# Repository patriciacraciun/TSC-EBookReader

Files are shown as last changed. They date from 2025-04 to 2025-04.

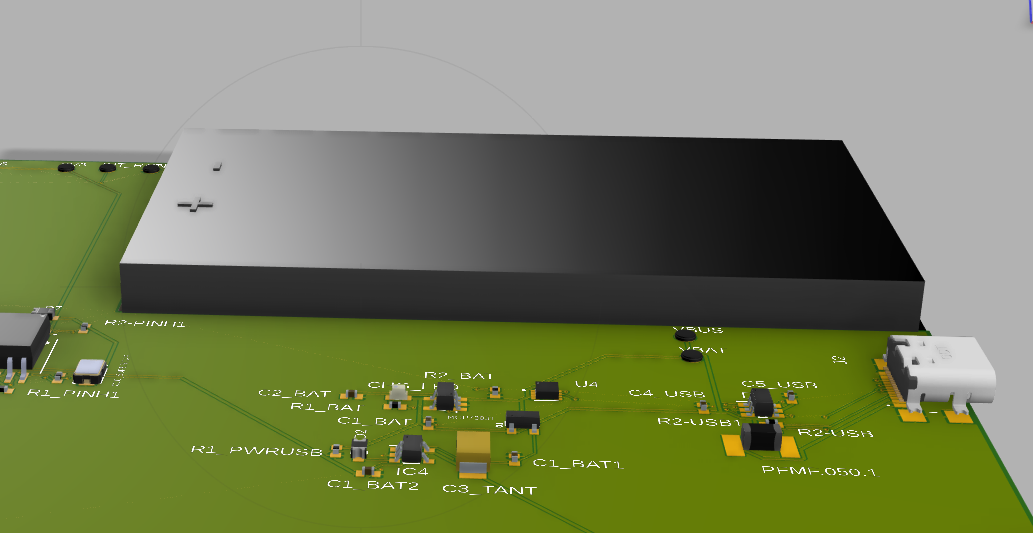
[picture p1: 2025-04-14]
Images/Screenshot 2025-04-14 140928.png

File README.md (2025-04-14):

# README 

## Descriere Generala

Acest proiect reprezinta un sistem integrat cu afisaj E-Paper, conectivitate wireless si mai multi senzori. Totul este construit in jurul microcontrollerului ESP32-C6, care ofera suport pentru WiFi 6 si Bluetooth LE.
Proiectul include atat partea de incarcare si monitorizare a bateriei, cat si stocare externa si masurare a conditiilor de mediu.

---

## Etapele de Implementare

- Am inceput cu realizarea schemei electrice, conectand toate componentele relevante la ESP32-C6.
- Apoi am trecut la layout-ul PCB-ului in 2D, unde am rutat liniile de date si alimentare.
- Am creat planuri de masa (GND plane) atat pe stratul superior, cat si inferior.
- Am folosit reguli custom pentru latimea traseelor de alimentare si distantele minime fata de alte semnale.
- Conectorii au fost pozitionati astfel incat sa fie usor accesibili (ex: Qwiic pentru senzori externi).
- Am adaugat pad-uri de test (TP) pentru debugging mai usor dupa asamblare.
- Am generat modele 3D pentru a verifica compatibilitatea mecanica si pozitionarea componentelor in carcasa.
---











## Diagrama Bloc

```text
         +------------+
         |  Baterie   |
         +------------+
               |
               v
       +----------------+
       |  Charging IC   |<-- USB-C
       +----------------+
               |
               v
       +----------------+
       |      LDO       | --> 3.3V
       +----------------+
               |
      +--------+--------+--------+--------+--------+
      v        v        v        v        v
   +------+ +--------+ +------+ +------+ +--------+
   | ESP  | |Display | | RTC  | | BME  | | Butoane|
   | -C6  | |(SPI)   | |(I2C) | |(I2C) | |(GPIO)  |
   +------+ +--------+ +------+ +------+ +--------+
               |
               v
           +---------+
           | Flash   |
           |  NOR    |
           | (SPI)   |
           +---------+
               |
               v
           +---------+
           | SD Card |
           |  (SPI)  |
           +---------+
```

---

## BOM (Bill Of Materials)

| Componenta | Link Cumparare | Datasheet 
|---|---|---
| 112A-TAAR-R03 ATTEND | https://store.comet.srl.ro/Catalogue/Product/43497/ | https://www.snapeda.com/parts/112A-TAAR-R03/Attend/datasheet/ 
| BD5229G-TR | https://www.digikey.com/en/products/detail/rohm-semiconductor/BD5229G-TR/3663792 | https://fscdn.rohm.com/en/products/databook/datasheet/ic/power/voltage_detector/bd52xxg-e.pdf 
| ESP32 WROVER BME680 Sensor | https://store.comet.srl.ro/Catalogue/Product/50164/ | https://www.bosch-sensortec.com/media/boschsensortec/downloads/datasheets/bst-bme680-ds001.pdf 
| LED CHG_LED | https://ro.mouser.com/ProductDetail/Kingbright/KP-1608SURCK?qs=2JU0tDl2GZ3FuyEWfBV1%2Fg== | https://www.snapeda.com/parts/KP-1608SURCK/Kingbright/datasheet/ 
| Condensator C0402 | https://ro.mouser.com/c/passive-components/capacitors/ceramic-capacitors/?q=CC0402 | https://componentsearchengine.com/Datasheets/2/CC0402MRX5R5BB106.pdf 
| Condensator Tant | https://ro.mouser.com/ProductDetail/KYOCERA-AVX/TAJW107M010RNJ?qs=Wtp%252Bf%2FAeVqIH8v1VxV%252B1Rg%3D%3D | https://ro.mouser.com/datasheet/2/40/TAJ-3165264.pdf 
| Q1 DMG2305UX-7 | https://www.digikey.com/en/products/detail/diodes-incorporated/DMG2305UX-7/4340666 | https://www.diodes.com/assets/Datasheets/DMG2305UX.pdf 
| RTC MODULE DS3231SN# | https://www.snapeda.com/parts/DS3231SN%23/Analog+Devices/view-part/?ref=eda | https://www.snapeda.com/parts/DS3231SN%23/Analog%20Devices/datasheet/ 
| ESP32 C6 WROOM-1-N8 | https://ro.mouser.com/ProductDetail/Espressif-Systems/ESP32-C6-WROOM-1-N8?qs=8Wlm6%252BaMh8ST02Gmwp74cw%3D%3D | https://www.snapeda.com/parts/ESP32-C6-WROOM-1-N8/Espressif%20Systems/datasheet/ 
| FH34SRJ-24S-0.5SH(99) | https://ro.mouser.com/ProductDetail/Hirose-Connector/FH34SRJ-24S-0.5SH99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 | https://www.snapeda.com/parts/FH34SRJ-24S-0.5SH(99)/Hirose%20Connector/datasheet/ 
| MAX 17048G+T10 | https://www.snapeda.com/parts/MAX17048G+T10/Analog+Devices/view-part/?ref=eda | https://www.snapeda.com/parts/MAX17048G+T10/Analog%20Devices/datasheet/ 
| MBR0530 Schottky Diode | https://www.snapeda.com/parts/MBR0530/Onsemi/view-part/?ref=snap | https://www.snapeda.com/parts/MBR0530/ON%20Semiconductor/datasheet/ 
| MCP73831 Power Management | https://www.snapeda.com/parts/MCP73831T-2ACI/OT/Microchip/datasheet/ | https://www.snapeda.com/parts/MCP73831T-2ACI/OT/Microchip/datasheet/ 
| PFMF.050.1 | https://ro.mouser.com/ProductDetail/EPCOS-TDK/B72520T0350K062?qs=dEfas%2FXlABIszF52uu7vrg%3D%3D | https://www.tdk-electronics.tdk.com/inf/75/db/CTVS_14/Surge_protection_series.pdf 
| PGB1010603MR | https://www.snapeda.com/parts/PGB1010603MR/Littelfuse/view-part/?ref=eda | https://www.snapeda.com/parts/PGB1010603MR/Littelfuse%20Inc./datasheet/ 
| QWIIC_RIGHT_ANGLE CONNECTOR | https://ro.mouser.com/ProductDetail/SparkFun/PRT-14417?qs=wd5RIQLrsJhgdz%2FpmZ%2F3GQ== | https://ro.mouser.com/datasheet/2/813/Qwiic_Connector_Datasheet-1223982.pdf 
| Rezistenta R0402 | https://grabcad.com/library/resistor-0402-1) | https://www.yageo.com/upload/media/product/products/datasheet/rchip/PYu-RC_Group_51_RoHS_L_12.pdf
| SD0805S020S1R0 | https://ro.mouser.com/ProductDetail/KYOCERA-AVX/SD0805S020S1R0?qs=jCA%252BPfw4LHbpkAoSnwrdjw%3D%3D | https://ro.mouser.com/datasheet/2/40/schottky-3165252.pdf 
| Si1308EDL-T1-GE3 MOSFET | https://www.snapeda.com/parts/SI1308EDL-T1-GE3/Vishay+Siliconix/view-part/?welcome=home&ref=eda | https://www.snapeda.com/parts/SI1308EDL-T1-GE3/Vishay%20Siliconix/datasheet/ 
| USB4110-GF-A | https://ro.mouser.com/ProductDetail/GCT/USB4110-GF-A?qs=KUoIvG%2F9IlYiZvIXQjyJeA%3D%3D | https://ro.mouser.com/datasheet/2/837/GCT_USB4110_Product_Drawing___20k_cycles-3455479.pdf 
| USBLC6-2SC6Y | https://ro.mouser.com/ProductDetail/STMicroelectronics/USBLC6-2SC6Y?qs=gNDSiZmRJS%2FOgDexvXkdow%3D%3D | https://ro.mouser.com/datasheet/2/389/usblc6_2sc6y-1852505.pdf 
| W25Q512JVEIQ | https://www.snapeda.com/parts/W25Q512JVEIQ/Winbond+Electronics/view-part/?ref=eda) | https://www.winbond.com/resource-files/W25Q512JV%20SPI%20RevB%2006252019%20KMS.pdf 
| XC6220A331MR-G | https://componentsearchengine.com/part-view/XC6220A331MR-G/Torex | https://product.torexsemi.com/system/files/series/xc6220.pdf 
| 744043680 BOBINA | https://ro.mouser.com/ProductDetail/Wurth-Elektronik/744043680?qs=PGXP4M47uW6VkZq%252BkzjrHA%3D%3D | https://www.we-online.com/components/products/datasheet/744043680.pdf 

---

## Functionalitate Hardware

Microcontrollerul ESP32-C6 gestioneaza toate functiile sistemului:

- **Display E-Paper**: conectat prin SPI. Este utilizat pentru afisajul principal.
- **BME688**: senzor de temperatura, umiditate, presiune si VOC, conectat prin I2C.
- **RTC DS3231**: modul de timp real, pentru pastrarea orei chiar si cand dispozitivul este oprit.
- **SD Card**: stocare externa, comunicare SPI.
- **Memorie NOR Flash**: pentru date si firmware, interfata SPI.
- **Charging controller (MCP73831)**: incarca bateria Li-Po prin USB-C.
- **Fuel gauge (MAX17048)**: monitorizeaza nivelul de incarcare al bateriei.
- **Qwiic Connector**: pentru senzori modulari, I2C.
- **Buton BOOT si RESET**: conectate la GPIO pentru programare si control.

---

## Alocarea Pinilor ESP32-C6

| Componenta | Interfata | Pini ESP32-C6 | Observatii |
|---|---|---|---|
| Display E-Paper | SPI | IO7, IO6, IO10, IO5, IO23, IO3 | MOSI, SCK, CS, DC, RST, BUSY |
| BME688 + RTC | I2C | IO21 (SDA), IO22 (SCL) | Bus comun cu pull-up |
| MAX17048 Battery Gauge | I2C | IO19 (SCL), IO20 (SDA)| Separat pentru alimentare baterie |
| SD Card | SPI | IO4 (CS) + MOSI/SCK/MISO| Partajate cu Flash/Display |
| Flash NOR | SPI | IO12 (CS) | Pe acelasi bus SPI |
| USB | USB | IO13 (D+), IO12 (D-)  | Conexiune directa la USB-C |
| Buton Reset | GPIO | EN | Reset hardware |
| Buton Boot | GPIO | IO9 | Intrare manuala in modul bootloader |

---

## Alte Observatii

- Placa are pad-uri de test (TP) pentru debugging usor.
- Conectorul Qwiic permite extinderea cu alti senzori.
- Diodele ESD protejeaza liniile sensibile (USB, SPI, alimentare).
- Planurile de masa au fost implementate pe ambele straturi pentru stabilitate si protectie EMI.
- Rutarea a fost facuta manual, tinand cont de distantele minime si traseele de putere.
- PCB-ul este compact si poate fi reprodus usor in mai multe exemplare.
- Designul este compatibil cu carcase printate 3D.

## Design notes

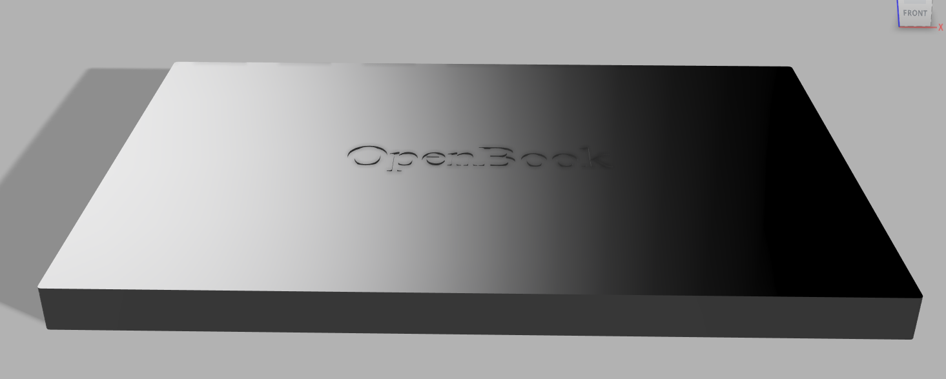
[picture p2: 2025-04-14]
Images/Screenshot 2025-04-14 141623.png

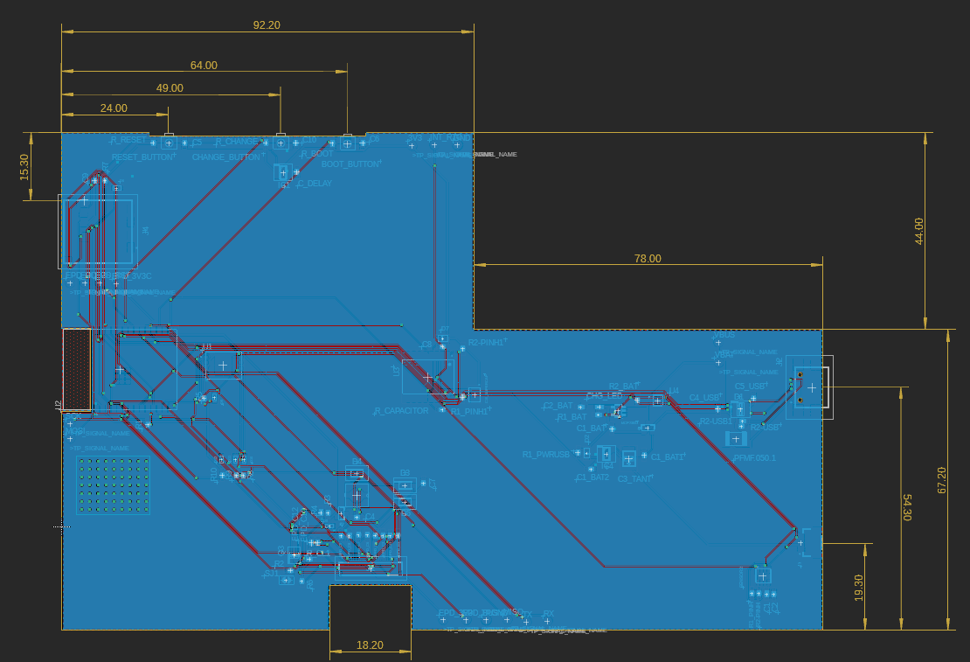
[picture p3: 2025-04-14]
Images/Screenshot 2025-04-14 141432.png

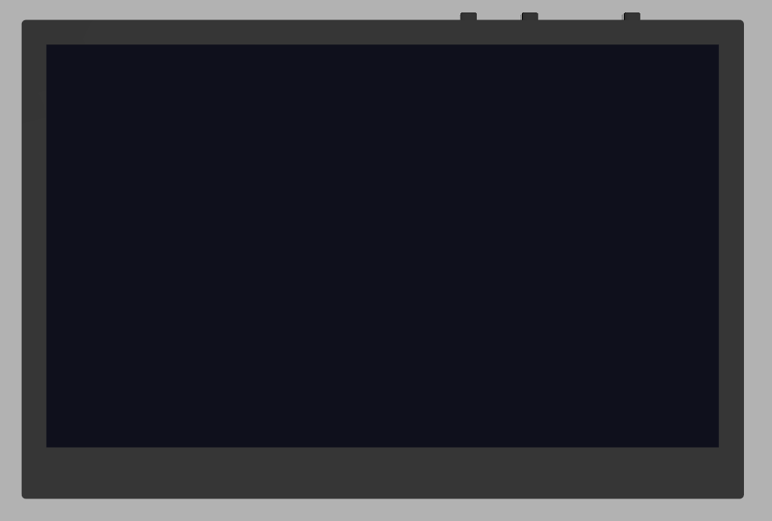
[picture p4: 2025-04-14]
Images/Screenshot 2025-04-14 141027.png

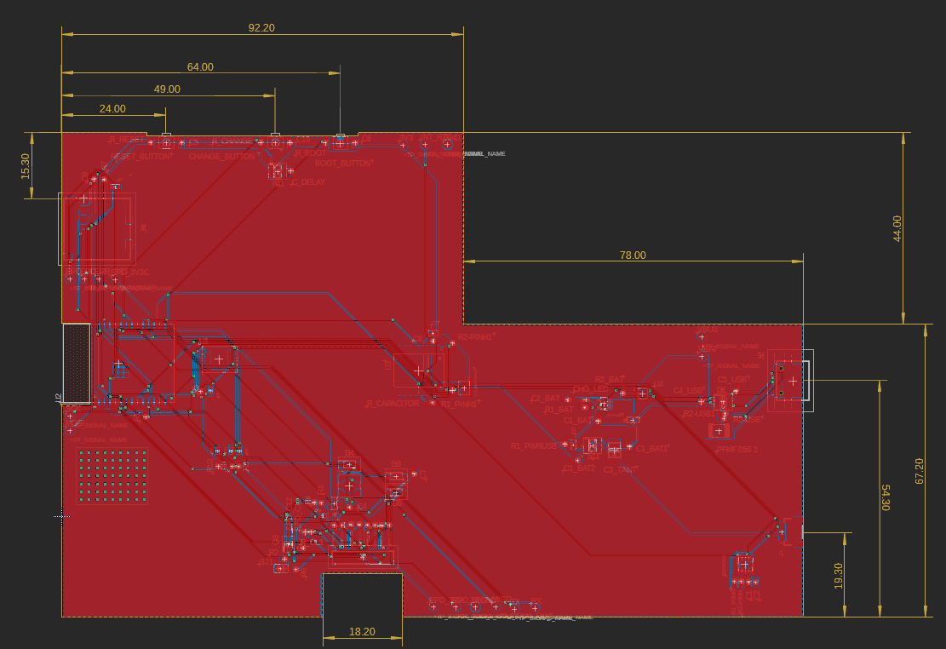
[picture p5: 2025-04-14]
Images/Screenshot 2025-04-14 141415.png

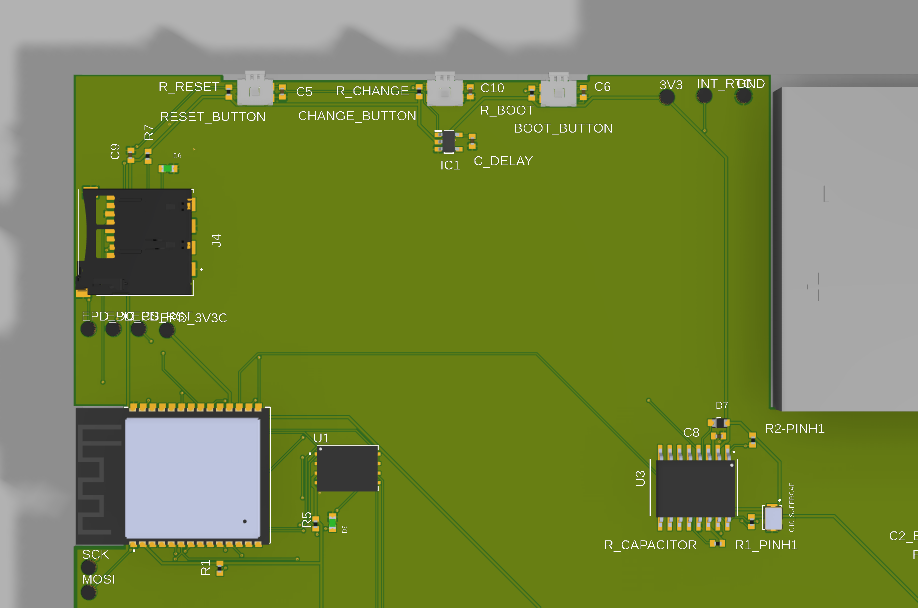
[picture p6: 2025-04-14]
Images/Screenshot 2025-04-14 140821.png

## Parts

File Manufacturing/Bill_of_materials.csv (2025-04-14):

Qty | Value | Device | Package | Parts | Description | ARROW_PART_NUMBER | ARROW_PRICE-STOCK | AVAILABILITY | CENTROID_NOT_SPECIFIED | CHECK_PRICES | COPYRIGHT | DATASHEET | DESCRIPTION | DIGIKEY_DESCRIPTION | DIGIKEY_PART_NUMBER | HEIGHT | L1 | LEAD_FREE | MANUFACTURER_NAME | MANUFACTURER_PART_NUMBER | MCP73831 | MF | MFR_NAME | MOUSER_PART_NUMBER | MOUSER_PRICE-STOCK | MOUSER_TESTING_PART_NUMBER | MOUSER_TESTING_PRICE-STOCK | MP | MPN | PACKAGE | POPULARITY | PREFIX | PRICE | PROD_ID | PURCHASE-URL | ROHS | SNAPEDA_LINK | SPICEPREFIX | TEMPERATURE_RANGE_HIGH | TEMPERATURE_RANGE_LOW | VALUE
1 |  | ADAFRUIT_LEDCHIP-LED0603 | ADAFRUIT_CHIP-LED0603 | CHG_LED | LED
1 |  | SJ | SJ | SJ1 | SMD solder JUMPER |  |  |  |  |  |  |  |  |  |  |  |  |  |  |  |  |  |  |  |  |  |  |  |  |  | 3
1 | 0.1uF/50V | EAGLE-LTSPICE_CC0402 | EAGLE-LTSPICE_C0402 | EPD_C5 | CAPACITOR, European symbol
1 | 0.47 | ESP32_WROVER_EAGLE-LTSPICE_RR0402 | ESP32_WROVER_EAGLE-LTSPICE_R0402 | R3 | RESISTOR, European symbol
1 | 100 nF | ESP32_WROVER_EAGLE-LTSPICE_CC0402 | ESP32_WROVER_EAGLE-LTSPICE_C0402 | C4_USB | CAPACITOR, European symbol
1 | 1000nF | EAGLE-LTSPICE_CC0402 | EAGLE-LTSPICE_C0402 | C8 | CAPACITOR, European symbol
1 | 100K | ESP32_WROVER_EAGLE-LTSPICE_RR0402 | ESP32_WROVER_EAGLE-LTSPICE_R0402 | R1_PWRUSB | RESISTOR, European symbol
4 | 100nF | EAGLE-LTSPICE_CC0402 | EAGLE-LTSPICE_C0402 | C6, C9, C10, C_DELAY | CAPACITOR, European symbol
2 | 100nF | ESP32_WROVER_EAGLE-LTSPICE_CC0402 | ESP32_WROVER_EAGLE-LTSPICE_C0402 | C1, C2 | CAPACITOR, European symbol
1 | 100uF | RCL_CPOL-EUCT3528 | RCL_CT3528 | C3_TANT | POLARIZED CAPACITOR, European symbol |  |  |  |  |  |  |  |  |  |  |  |  |  |  |  |  |  |  |  |  |  |  |  |  |  | 0 |  |  |  |  |  |  | C
16 | 10K | ESP32_WROVER_EAGLE-LTSPICE_RR0402 | ESP32_WROVER_EAGLE-LTSPICE_R0402 | R1, R1_PINH, R1_PINH1, R2-PINH, R2-PINH1, R4, R5, R6, R7, R8, R9, R10, R_BOOT, R_CHANGE, R_CL1, R_RESET | RESISTOR, European symbol
1 | 10uF | EAGLE-LTSPICE_CC0402 | EAGLE-LTSPICE_C0402 | C7 | CAPACITOR, European symbol
1 | 112A-TAAR-R03_ATTEND | 112A-TAAR-R03_ATTEND | 112ATAARR03ATTEND | J4 | Micro SD Card Socket, Push-Push Type, Top Mount, SMT, H=1.83mm, 10u |  |  |  |  |  |  |  | Micro SD Card Socket | Push-Push Type | Top Mount | SMT | H=1.83mm | 10u |  |  | 1.9mm |  |  | ATTEND | 112A-TAAR-R03 ATTEND
1 | 15 | ESP32_WROVER_EAGLE-LTSPICE_RR0402 | ESP32_WROVER_EAGLE-LTSPICE_R0402 | R_CAPACITOR | RESISTOR, European symbol
1 | 1uF | EAGLE-LTSPICE_CC0402 | EAGLE-LTSPICE_C0402 | C5 | CAPACITOR, European symbol
9 | 1uF/50V | EAGLE-LTSPICE_CC0402 | EAGLE-LTSPICE_C0402 | EPD_C1, EPD_C2, EPD_C6, EPD_C7, EPD_C8, EPD_C9, EPD_C10, EPD_C11, EPD_C12 | CAPACITOR, European symbol
1 | 2.2 | ESP32_WROVER_EAGLE-LTSPICE_RR0402 | ESP32_WROVER_EAGLE-LTSPICE_R0402 | R2 | RESISTOR, European symbol
1 | 200 | ESP32_WROVER_EAGLE-LTSPICE_RR0402 | ESP32_WROVER_EAGLE-LTSPICE_R0402 | R1_BAT | RESISTOR, European symbol
2 | 20V/4.2A/52mO/1.4W | ESP32_WROVER_SPARKFUN-DISCRETESEMI_MOSFET_PCH-DMG2305UX-7 | ESP32_WROVER_SPARKFUN-DISCRETESEMI_SOT23-3 | Q1, Q2 | P-channel MOSFETs |  |  |  |  |  |  |  |  |  |  |  |  |  |  |  |  |  |  |  |  |  |  |  |  |  |  |  |  | TRAN-14388 |  |  |  |  |  |  | 20V/4.2A/52mO/1.4W
1 | 2K | ESP32_WROVER_EAGLE-LTSPICE_RR0402 | ESP32_WROVER_EAGLE-LTSPICE_R0402 | R2_BAT | RESISTOR, European symbol
4 | 4.7uF | EAGLE-LTSPICE_CC0402 | EAGLE-LTSPICE_C0402 | C1_BAT, C1_BAT1, C1_BAT2, C2_BAT | CAPACITOR, European symbol
1 | 4.7uF | ESP32_WROVER_EAGLE-LTSPICE_CC0402 | ESP32_WROVER_EAGLE-LTSPICE_C0402 | C5_USB | CAPACITOR, European symbol
1 | 4.7uF/25V | EAGLE-LTSPICE_CC0402 | EAGLE-LTSPICE_C0402 | C4 | CAPACITOR, European symbol
1 | 5K1 | ESP32_WROVER_EAGLE-LTSPICE_RR0402 | ESP32_WROVER_EAGLE-LTSPICE_R0402 | R2-USB | RESISTOR, European symbol
1 | 5k1 | ESP32_WROVER_EAGLE-LTSPICE_RR0402 | ESP32_WROVER_EAGLE-LTSPICE_R0402 | R2-USB1 | RESISTOR, European symbol
1 | 744043680IND_4828-WE-TPC_WRE | 744043680IND_4828-WE-TPC_WRE | IND_4828-WE-TPC_WRE | L1 |  |  |  |  |  |  | Copyright (C) 2024 Ultra Librarian. All rights reserved. |  |  |  |  |  | 68uH |  |  | 744043680 |  |  | Wurth Electronics
1 | BD5229G-TR | BD5229G-TR | SOT95P280X125-5N | IC1 | Voltage Detector with Adjustable Delay Time: CMOS processes are utilized to develop high precision, low current consumption CMOS reset ICs that allow arbitrary setting of the delay time. The extensive lineup includes both Nch Open Drain and CMOS output types in a wide range of detection voltages (from 2.3V to 6.0V, in 0.1V steps), enabling selection of the ideal solution based on customer requirements. In addition, the entire series is of course both lead-free and RoHS-compliant. |  |  |  |  |  |  |  | Voltage Detector with Adjustable Delay Time: CMOS processes are utilized to develop high precision | low current consumption CMOS reset ICs that allow arbitrary setting of the delay time. The extensive lineup includes both Nch Open Drain and CMOS output types in a wide range of detection voltages (from 2.3V to 6.0V | in 0.1V steps) | enabling selection of the ideal solution based on customer requirements. In addition | the entire series is of course both lead-free and RoHS-compliant. |  |  | 1.25mm |  |  | ROHM Semiconductor | BD5229G-TR |  |  |  | 755-BD5229G-TR | https://www.mouser.co.uk/ProductDetail/ROHM-Semiconductor/BD5229G-TR?qs=4kLU8WoGk0vvnhrrYwdszw%3D%3D
3 | BUTTON_CUSYOMV1 | BUTTON_CUSYOMV1 | MYBUTTON | BOOT_BUTTON, CHANGE_BUTTON, RESET_BUTTON
1 | CPH3225A | CPH3225A | CAPCP3225X100N | C10_SUPERCAP | Cap 0.011F 3.3V 1210 Flat Check availability |  |  | Not in stock |  | https://www.snapeda.com/parts/CPH3225A/Seiko+Instruments/view-part/?ref=eda |  |  | 11 mF (EDLC) Supercapacitor 3.3 V 1210 (3225 Metric) - - |  |  |  |  |  |  |  |  | Seiko Instruments |  |  |  |  |  | CPH3225A |  | 1210 Seiko |  |  | None |  | https://www.snapeda.com/api/url_track_click_mouser/?unipart_id=562593&manufacturer=Seiko Instruments&part_name=CPH3225A&search_term=None |  | https://www.snapeda.com/parts/CPH3225A/Seiko+Instruments/view-part/?ref=snap
1 | DS3231SN# | DS3231SN# | SOIC127P1032X265-16N | U3 | Real Time Clock Serial 16-Pin SOIC W T/R Check availability |  |  | In Stock |  | https://www.snapeda.com/parts/DS3231SN%23/Analog+Devices/view-part/?ref=eda |  |  | Extremely Accurate I²C-Integrated RTC/TCXO/Crystal |  |  |  |  |  |  |  |  | Analog Devices |  |  |  |  |  | DS3231SN# |  | SOIC-16 Maxim |  |  | None |  | https://www.snapeda.com/api/url_track_click_mouser/?unipart_id=99048&manufacturer=Analog Devices&part_name=DS3231SN#&search_term=None |  | https://www.snapeda.com/parts/DS3231SN%23/Analog+Devices/view-part/?ref=snap
1 | ESP32-C6-WROOM-1-N8 | ESP32-C6-WROOM-1-N8 | XCVR_ESP32-C6-WROOM-1-N8 | U2 | Check availability |  |  | In Stock |  | https://www.snapeda.com/parts/ESP32-C6-WROOM-1-N8/Espressif+Systems/view-part/?ref=eda |  |  | Multiprotocol Modules ESP32-C6 module | Wi-Fi 6 in 2.4 GHz band | Bluetooth 5 | Zigbee 3.0 and Thread. ESP34-WROOM Compatible - ENGINEERING SAMPLE |  |  |  |  |  |  |  |  | Espressif Systems |  |  |  |  |  | ESP32-C6-WROOM-1-N8 |  | None |  |  | None |  |  |  | https://www.snapeda.com/parts/ESP32-C6-WROOM-1-N8/Espressif+Systems/view-part/?ref=snap
1 | ESP32C6_VARISTORCN1812 | ESP32C6_VARISTORCN1812 | ESP32C6_VARISTOR_CT/CN1812 | PFMF.050.1 | VARISTOR |  |  |  |  |  |  |  |  |  |  |  |  |  |  |  |  |  |  |  |  |  |  |  |  |  | 0
2 | ESP32_WROVER_AVX---SD0805S020S1R0_AVX_SD0805S020S1R0_0_0AVX_SD0805S020S1R0_0_0 | ESP32_WROVER_AVX---SD0805S020S1R0_AVX_SD0805S020S1R0_0_0AVX_SD0805S020S1R0_0_0 | ESP32_WROVER_AVX---SD0805S020S1R0_AVX_SD0805S020S1R0_0 | D2, D7 | Schottky Barrier Rectifier Diode |  |  |  | No |  |  | http://datasheets.avx.com/schottky.pdf |  | DIODE SCHOTTKY 20V 1A 0805 | 478-7800-1-ND |  |  | yes |  |  |  | AVX |  | 581-SD0805S020S1R0 |  |  |  |  |  | 0805 (2012 metric) |  | D |  |  |  | yes |  |  | +125°C | -55°C
1 | ESP32_WROVER_BME680_BME680 | ESP32_WROVER_BME680_BME680 | ESP32_WROVER_BME680_PSON80P300X300X100-8N | SENSOR2 | Integrated Environmental Unit |  |  | Unavailable |  |  |  |  | Integrated Environmental Unit |  |  |  |  |  |  |  |  | Bosch Sensortec |  |  |  |  |  | BME680 |  | LGA-8 Bosch Tools |  |  | None
1 | ESP32_WROVER_SPARKFUN-IC-POWER_MCP73831 | ESP32_WROVER_SPARKFUN-IC-POWER_MCP73831 | ESP32_WROVER_SPARKFUN-IC-POWER_SOT23-5 | MCP73831 | MCP73831T Li-Ion, Li-Pol Controller |  |  |  |  |  |  |  |  |  |  |  |  |  |  |  |  |  |  |  |  |  |  |  |  |  |  |  |  | IC-09995
1 | FH34SRJ-24S-0.5SH_99_ | FH34SRJ-24S-0.5SH_99_ | FH34SRJ24S05SH99 | J1 | (0.50mm) Surface Mount, Right Angle |  |  |  |  |  |  |  | 24 Position FFC | FPC Connector Contacts | (0.50mm) Surface Mount | Right Angle |  |  | 1.1mm |  |  | Hirose | FH34SRJ-24S-0.5SH(99) |  |  |  | 798-FH34SRJ24S05SH99 | https://www.mouser.co.uk/ProductDetail/Hirose-Connector/FH34SRJ-24S-0.5SH99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
1 | MAX17048G+T10 | MAX17048G+T10 | SON50P200X200X80-9N | U4 | Check availability |  |  | In Stock |  | https://www.snapeda.com/parts/MAX17048G+T10/Analog+Devices/view-part/?ref=eda |  |  | 3µA 1-Cell/2-Cell Fuel Gauge with ModelGauge |  |  |  |  |  |  |  |  | Analog Devices |  |  |  |  |  | MAX17048G+T10 |  | TDFN-8 Maxim |  |  | None |  | https://www.snapeda.com/api/url_track_click_mouser/?unipart_id=329239&manufacturer=Analog Devices&part_name=MAX17048G+T10&search_term=None |  | https://www.snapeda.com/parts/MAX17048G+T10/Analog+Devices/view-part/?ref=snap
3 | MBR0530 | MBR0530 | SOD3716X135N | D3, D4, D5 | ON SEMICONDUCTOR - MBR0530 - DIODE, SCHOTTKY, 0.5A, 30V, SOD-123 |  |  | In Stock |  | https://www.snapeda.com/parts/MBR0530/Onsemi/view-part/?ref=eda |  |  | Diode Schottky 30 V 500mA Surface Mount SOD-123 |  |  |  |  |  |  |  |  | ON Semiconductor |  |  |  |  |  | MBR0530 |  | SOD-123-2 ON Semiconductor |  |  | None |  | https://www.snapeda.com/api/url_track_click_mouser/?unipart_id=179458&manufacturer=ON Semiconductor&part_name=MBR0530&search_term=None |  | https://www.snapeda.com/parts/MBR0530/Onsemi/view-part/?ref=snap
6 |  |  | DIOC1608X36N | D6, D8, D9, D10, D11, D12 | Check availability
1 | QWIIC_RIGHT_ANGLE | QWIIC_CONNECTORJS-1MM | JST04_1MM_RA | J3 | SparkFun I2C Standard Qwiic Connector |  |  |  |  |  |  |  |  |  |  |  |  |  |  |  |  |  |  |  |  |  |  |  |  |  |  |  |  | CONN-13694 |  |  |  |  |  |  | QWIIC_RIGHT_ANGLE
1 | SAMACSYS_PARTS_USB4110-GF-A | SAMACSYS_PARTS_USB4110-GF-A | SAMACSYS_PARTS_USB4110GFA | J2 | CONN USB 2.0 TYPE-C R/A SMT |  |  |  |  |  |  |  | CONN USB 2.0 TYPE-C R/A SMT |  |  | 3.26mm |  |  | GCT (GLOBAL CONNECTOR TECHNOLOGY) | USB4110-GF-A |  |  |  | 640-USB4110-GF-A | https://www.mouser.co.uk/ProductDetail/GCT/USB4110-GF-A?qs=KUoIvG%2F9IlYiZvIXQjyJeA%3D%3D
1 | SI1308EDL-T1-GE3 | SI1308EDL-T1-GE3 | SOT65P210X110-3N | Q3 | MOSFET N-Ch 30V 1.5A TrenchFET SC70 Vishay Si1308EDL-T1-GE3 N-channel MOSFET Transistor, 1.5 A, 30 V, 3-Pin SC-70 |  |  | In Stock |  | https://www.snapeda.com/parts/SI1308EDL-T1-GE3/Vishay+Siliconix/view-part/?ref=eda |  |  | Si1308EDL-T1-GE3 N-channel MOSFET Transistor | 1.5 A | 30 V | 3-Pin SC-70 | Siliconix / Vishay SI1308EDL-T1-GE3 |  |  |  |  |  |  |  |  | Vishay Siliconix |  |  |  |  |  | SI1308EDL-T1-GE3 |  | SOT-323 Vishay Semiconductor |  |  | None |  | https://www.snapeda.com/api/url_track_click_mouser/?unipart_id=274603&manufacturer=Vishay Siliconix&part_name=SI1308EDL-T1-GE3&search_term=None |  | https://www.snapeda.com/parts/SI1308EDL-T1-GE3/Vishay+Siliconix/view-part/?ref=snap
17 | TPTP20R | TPTP20R | TP20R | 3V3, EPD_3V3, EPD_3V3C, EPD_BUSY, EPD_CS, EPD_DC, EPD_RST, GND, INT_RTC, MISO, MOSI, RX, SCK, TPGND, TX, VBAT, VBUS | Test pad
1 | USBLC6-2SC6Y | USBLC6-2SC6Y | SOT95P280X145-6N | D1 | Low Cap. ESD Protection Auto SOT-23-6 STMicroelectronics USBLC6-2SC6Y, Dual Uni-Directional TVS Diode Array, 6-Pin SOT-23 |  |  | In Stock |  | https://www.snapeda.com/parts/USBLC6-2SC6Y/STMicroelectronics/view-part/?ref=eda |  |  | 17V Clamp 5A (8/20µs) Ipp Tvs Diode Surface Mount SOT-23-6 |  |  |  |  |  |  |  |  | STMicroelectronics |  |  |  |  |  | USBLC6-2SC6Y |  | SOT-23-6 STMicroelectronics |  |  | None |  |  |  | https://www.snapeda.com/parts/USBLC6-2SC6Y/STMicroelectronics/view-part/?ref=snap
1 | W25Q512JVEIQ | W25Q512JVEIQ | SON127P600X800X80-9N | U1 | Check availability |  |  | In Stock |  | https://www.snapeda.com/parts/W25Q512JVEIQ/Winbond+Electronics/view-part/?ref=eda |  |  | FLASH - NOR Memory IC 512Mb (64M x 8) SPI - Quad I/O 133 MHz 8-WSON (8x6) |  |  |  |  |  |  |  |  | Winbond Electronics |  |  |  |  |  | W25Q512JVEIQ |  | Package |  |  | None |  |  |  | https://www.snapeda.com/parts/W25Q512JVEIQ/Winbond+Electronics/view-part/?ref=snap
1 | XC6220A331MR-G | XC6220A331MR-G | SOT95P280X120-5N | IC4 | LDO Voltage Regulators |  |  |  |  |  |  |  | LDO Voltage Regulators |  |  | 1.2mm |  |  | Torex | XC6220A331MR-G |  |  |  | 865-XC6220A331MR-G | https://www.mouser.co.uk/ProductDetail/Torex-Semiconductor/XC6220A331MR-G?qs=AsjdqWjXhJ8ZSWznL1J0gg%3D%3D

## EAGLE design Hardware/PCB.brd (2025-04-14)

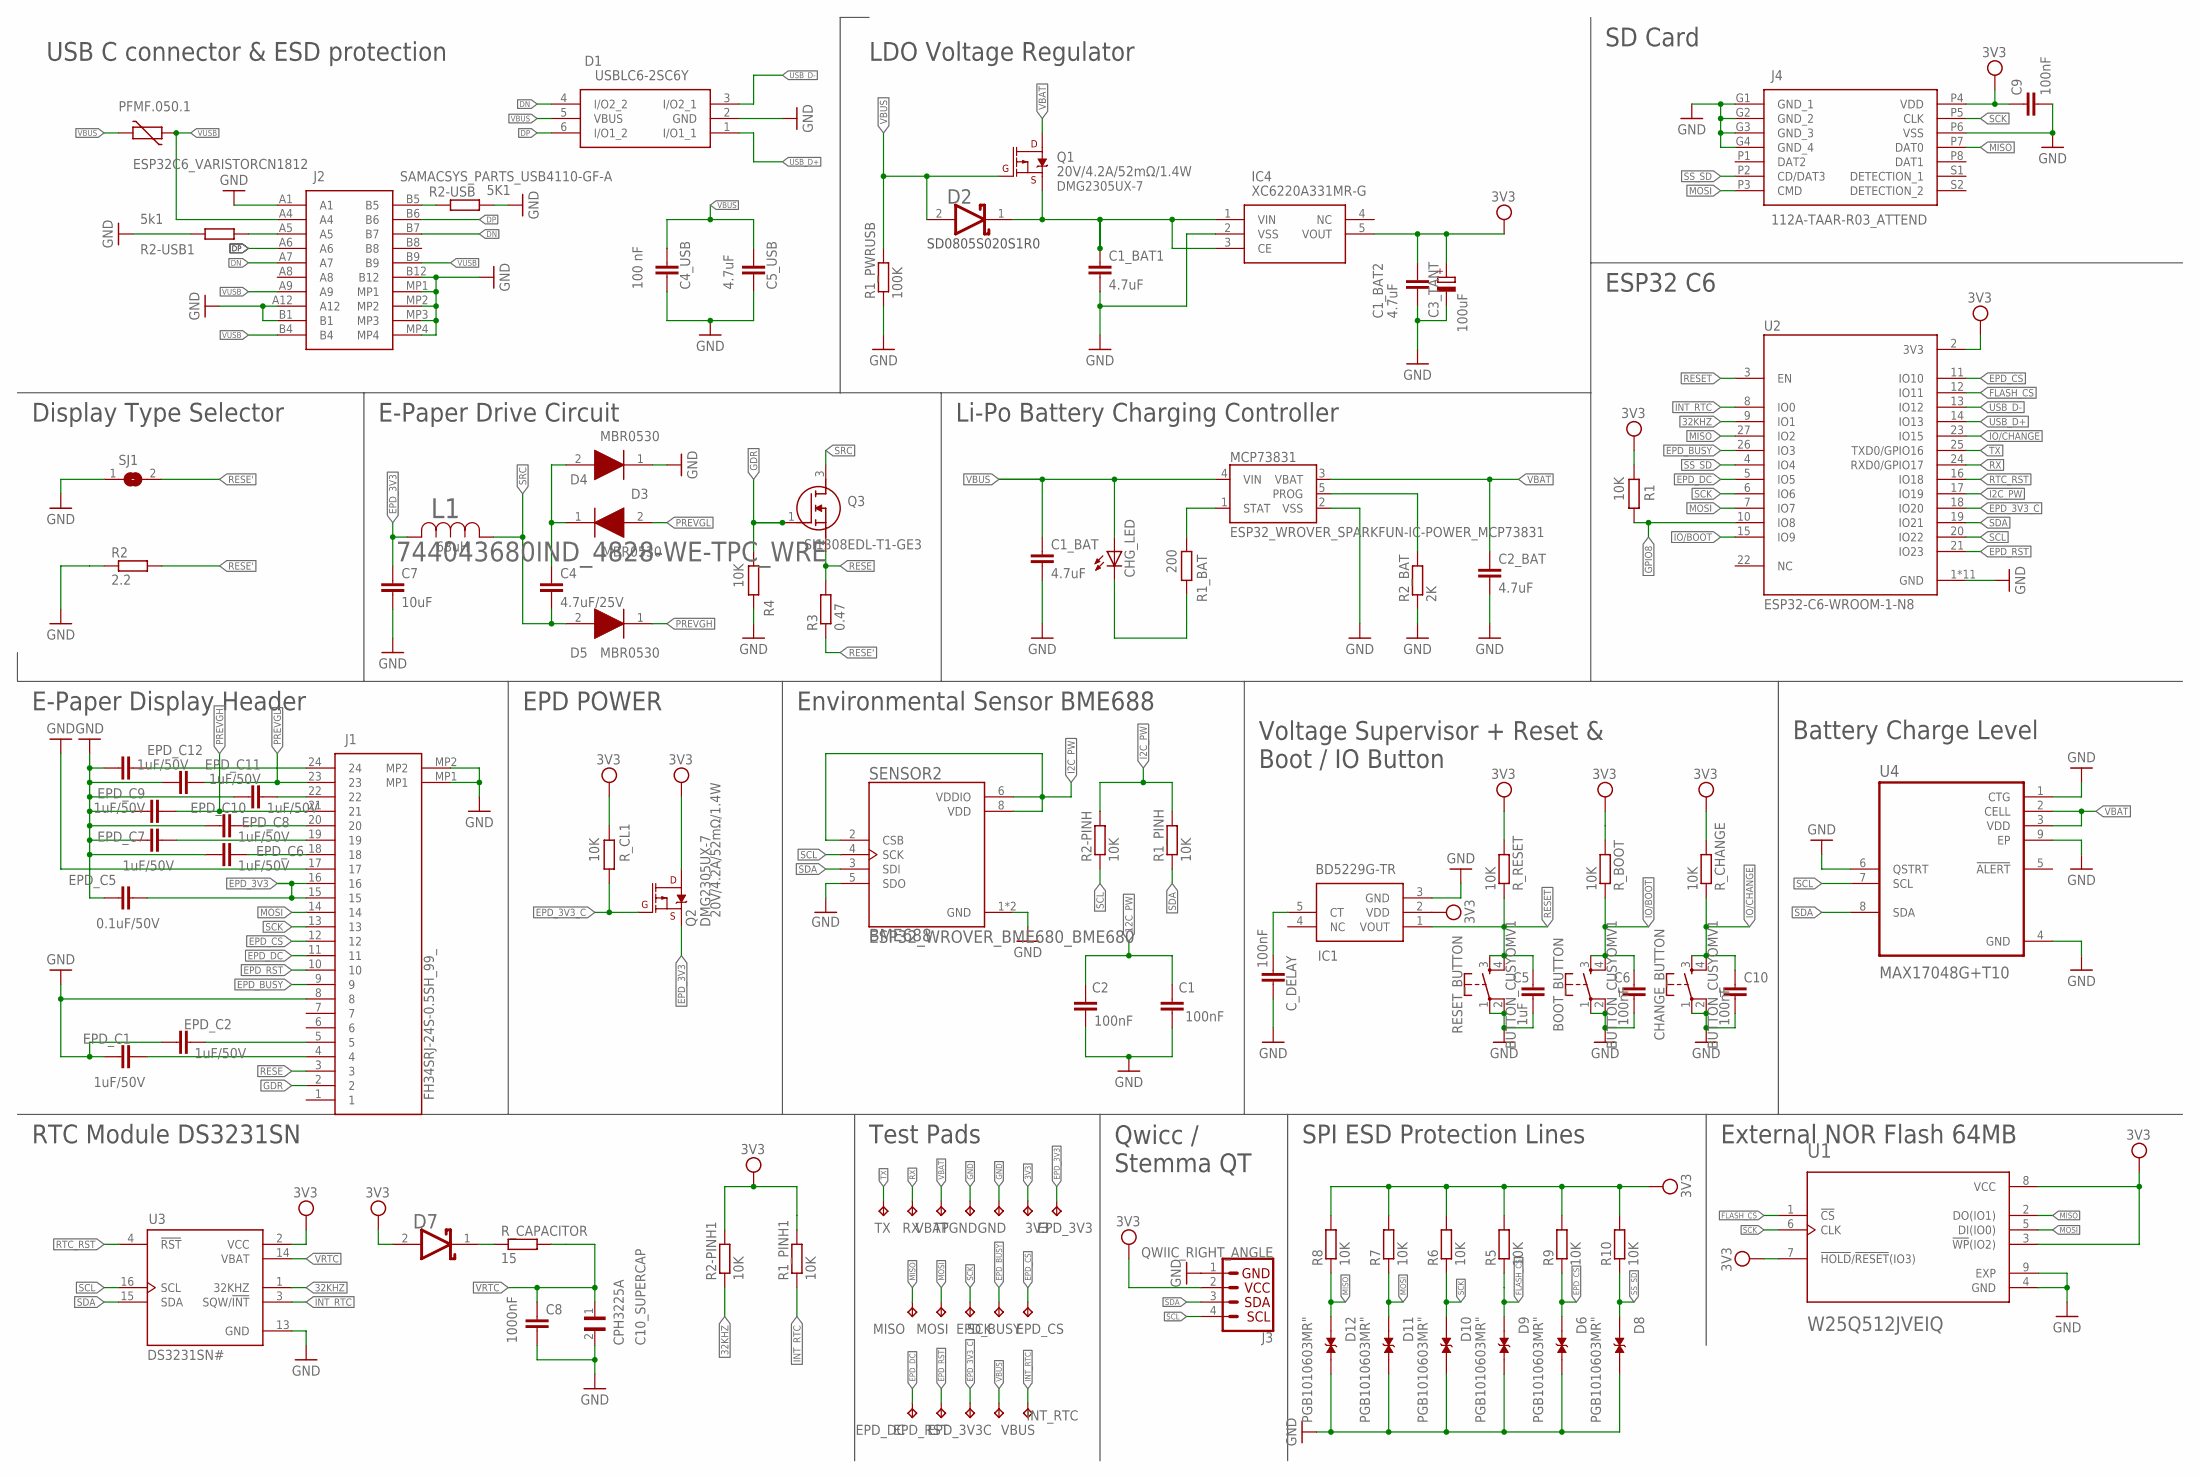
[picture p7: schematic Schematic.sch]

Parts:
3V3: TPTP20R; TP20R
BOOT_BUTTON: BUTTON_CUSYOMV1; MYBUTTON
C1, C2: 100nF; ESP32_WROVER_EAGLE-LTSPICE_C0402
C1_BAT, C1_BAT1, C1_BAT2, C2_BAT: 4.7uF; EAGLE-LTSPICE_C0402
C3_TANT: 100uF; RCL_CT3528
C4: 4.7uF/25V; EAGLE-LTSPICE_C0402
C4_USB: 100 nF; ESP32_WROVER_EAGLE-LTSPICE_C0402
C5: 1uF; EAGLE-LTSPICE_C0402
C5_USB: 4.7uF; ESP32_WROVER_EAGLE-LTSPICE_C0402
C6, C9, C10: 100nF; EAGLE-LTSPICE_C0402
C7: 10uF; EAGLE-LTSPICE_C0402
C8: 1000nF; EAGLE-LTSPICE_C0402
C10_SUPERCAP: CPH3225A; CAPCP3225X100N
CHANGE_BUTTON: BUTTON_CUSYOMV1; MYBUTTON
CHG_LED: ADAFRUIT_LEDCHIP-LED0603; ADAFRUIT_CHIP-LED0603
C_DELAY: 100nF; EAGLE-LTSPICE_C0402
D1: USBLC6-2SC6Y; SOT95P280X145-6N
D2, D7: ESP32_WROVER_AVX---SD0805S020S1R0_AVX_SD0805S020S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; ESP32_WROVER_AVX---SD0805S020S1R0_AVX_SD0805S020S1R0_0
D3, D4, D5: MBR0530; SOD3716X135N
D6, D8, D9, D10, D11, D12: PGB1010603MR"; DIOC1608X36N
EPD_3V3, EPD_3V3C: TPTP20R; TP20R
EPD_BUSY: TPTP20R; TP20R
EPD_C1, EPD_C2, EPD_C6, EPD_C7, EPD_C8, EPD_C9, EPD_C10, EPD_C11, EPD_C12: 1uF/50V; EAGLE-LTSPICE_C0402
EPD_C5: 0.1uF/50V; EAGLE-LTSPICE_C0402
EPD_CS: TPTP20R; TP20R
EPD_DC: TPTP20R; TP20R
EPD_RST: TPTP20R; TP20R
GND: TPTP20R; TP20R
IC1: BD5229G-TR; SOT95P280X125-5N
IC4: XC6220A331MR-G; SOT95P280X120-5N
INT_RTC: TPTP20R; TP20R
J1: FH34SRJ-24S-0.5SH_99_; FH34SRJ24S05SH99
J2: SAMACSYS_PARTS_USB4110-GF-A; SAMACSYS_PARTS_USB4110GFA
J3: QWIIC_RIGHT_ANGLE; JST04_1MM_RA
J4: 112A-TAAR-R03_ATTEND; 112ATAARR03ATTEND
L1: 744043680IND_4828-WE-TPC_WRE; IND_4828-WE-TPC_WRE
MCP73831: ESP32_WROVER_SPARKFUN-IC-POWER_MCP73831; ESP32_WROVER_SPARKFUN-IC-POWER_SOT23-5
MISO: TPTP20R; TP20R
MOSI: TPTP20R; TP20R
PFMF.050.1: ESP32C6_VARISTORCN1812; ESP32C6_VARISTOR_CT/CN1812
Q1, Q2: 20V/4.2A/52mΩ/1.4W; ESP32_WROVER_SPARKFUN-DISCRETESEMI_SOT23-3
Q3: SI1308EDL-T1-GE3; SOT65P210X110-3N
R1, R1_PINH, R1_PINH1, R2-PINH, R2-PINH1, R4, R5, R6, R7, R8, R9, R10: 10K; ESP32_WROVER_EAGLE-LTSPICE_R0402
R1_BAT: 200; ESP32_WROVER_EAGLE-LTSPICE_R0402
R1_PWRUSB: 100K; ESP32_WROVER_EAGLE-LTSPICE_R0402
R2: 2.2; ESP32_WROVER_EAGLE-LTSPICE_R0402
R2-USB: 5K1; ESP32_WROVER_EAGLE-LTSPICE_R0402
R2-USB1: 5k1; ESP32_WROVER_EAGLE-LTSPICE_R0402
R2_BAT: 2K; ESP32_WROVER_EAGLE-LTSPICE_R0402
R3: 0.47; ESP32_WROVER_EAGLE-LTSPICE_R0402
RESET_BUTTON: BUTTON_CUSYOMV1; MYBUTTON
RX: TPTP20R; TP20R
R_BOOT: 10K; ESP32_WROVER_EAGLE-LTSPICE_R0402
R_CAPACITOR: 15; ESP32_WROVER_EAGLE-LTSPICE_R0402
R_CHANGE: 10K; ESP32_WROVER_EAGLE-LTSPICE_R0402
R_CL1: 10K; ESP32_WROVER_EAGLE-LTSPICE_R0402
R_RESET: 10K; ESP32_WROVER_EAGLE-LTSPICE_R0402
SCK: TPTP20R; TP20R
SENSOR2: ESP32_WROVER_BME680_BME680; ESP32_WROVER_BME680_PSON80P300X300X100-8N
SJ1: SJ
TPGND: TPTP20R; TP20R
TX: TPTP20R; TP20R
U1: W25Q512JVEIQ; SON127P600X800X80-9N
U2: ESP32-C6-WROOM-1-N8; XCVR_ESP32-C6-WROOM-1-N8
U3: DS3231SN#; SOIC127P1032X265-16N
U4: MAX17048G+T10; SON50P200X200X80-9N
VBAT: TPTP20R; TP20R
VBUS: TPTP20R; TP20R

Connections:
3V3: 3V3.TP, C1_BAT2.1, C3_TANT.+, C9.1, D7.2 (ANODE), IC1.2 (VDD), IC4.5 (VOUT), J3.2, J4.P4 (VDD), Q2.3 (D), R1.2, R1_PINH1.2, R2-PINH1.2, R5.2, R6.2, R7.2, R8.2, R9.2, R10.2, R_BOOT.2, R_CHANGE.2, R_CL1.2, R_RESET.2, U1.3 (!WP!(IO2)), U1.7 (!HOLD!/!RESET!(IO3)), U1.8 (VCC), U2.2 (3V3), U3.2 (VCC)
12C_PW: C1.1, C2.1
32KHZ: R2-PINH1.1, U2.9 (IO1), U3.1 (32KHZ)
DMG2305UX-7: C1_BAT1.1, D2.1 (CATHODE), IC4.1 (VIN), IC4.3 (CE), Q1.2 (S)
DN: D1.4 (I/O2_2), J2.A7, J2.B7
DP: D1.6 (I/O1_2), J2.A6, J2.B6
EPD_3V3: C7.1, EPD_3V3.TP, EPD_C5.2, J1.15, J1.16, L1.2, Q2.2 (S)
EPD_3V3_C: EPD_3V3C.TP, Q2.1 (G), R_CL1.1, U2.18 (IO20)
EPD_BUSY: EPD_BUSY.TP, J1.9, U2.26 (IO3)
EPD_CS: D6.1, EPD_CS.TP, J1.12, R9.1, U2.11 (IO10)
EPD_DC: EPD_DC.TP, J1.11, U2.5 (IO5)
EPD_RST: EPD_RST.TP, J1.10, U2.21 (IO23)
FLASH_CS: D9.1, R5.1, U1.1 (!CS), U2.12 (IO11)
GDR: J1.2, Q3.1 (G), R4.2
GND: BOOT_BUTTON.1, BOOT_BUTTON.2, C1.2, C1_BAT.2, C1_BAT1.2, C1_BAT2.2, C2.2, C2_BAT.2, C3_TANT.-, C4_USB.2, C5.2, C5_USB.2, C6.2, C7.2, C8.2, C9.2, C10.2, C10_SUPERCAP.2, CHANGE_BUTTON.1, CHANGE_BUTTON.2, C_DELAY.2, D1.2 (GND), D4.1 (K), D6.2, D8.2, D9.2, D10.2, D11.2, D12.2, EPD_C1.1, EPD_C2.1, EPD_C5.1, EPD_C6.1, EPD_C7.1, EPD_C8.1, EPD_C9.1, EPD_C10.1, EPD_C11.1, EPD_C12.1, GND.TP, IC1.3 (GND), IC4.2 (VSS), J1.8, J1.17, J1.MP1, J1.MP2, J2.A1, J2.A12, J2.B1, J2.B12, J2.MP1, J2.MP2, J2.MP3, J2.MP4, J3.1, J4.G1 (GND_1), J4.G2 (GND_2), J4.G3 (GND_3), J4.G4 (GND_4), J4.P6 (VSS), MCP73831.2 (VSS), R1_PWRUSB.1, R2.1, R2-USB.2, R2-USB1.1, R2_BAT.1, R4.1, RESET_BUTTON.1, RESET_BUTTON.2, SENSOR2.1 (GND), SENSOR2.5 (SDO), SENSOR2.7 (GND), SJ1.1, TPGND.TP, U1.4 (GND), U1.9 (EXP), U2.1 (GND), U2.28 (GND), U2.29_1 (GND), U2.29_2 (GND), U2.29_3 (GND), U2.29_4 (GND), U2.29_5 (GND), U2.29_6 (GND), U2.29_7 (GND), U2.29_8 (GND), U2.29_9 (GND), U3.13 (GND), U4.1 (CTG), U4.4 (GND), U4.6 (QSTRT), U4.9 (EP)
GPIO8: R1.1, U2.10 (IO8)
I2C_PW: R1_PINH.2, R2-PINH.2, SENSOR2.2 (CSB), SENSOR2.6 (VDDIO), SENSOR2.8 (VDD), U2.17 (IO19)
INT_RTC: INT_RTC.TP, R1_PINH1.1, U2.8 (IO0), U3.3 (SQW/!INT)
IO/BOOT: BOOT_BUTTON.3, BOOT_BUTTON.4, C6.1, R_BOOT.1, U2.15 (IO9)
IO/CHANGE: C10.1, CHANGE_BUTTON.3, CHANGE_BUTTON.4, R_CHANGE.1, U2.23 (IO15)
MISO: D12.1, J4.P7 (DAT0), MISO.TP, R8.1, U1.2 (DO(IO1)), U2.27 (IO2)
MOSI: D11.1, J1.14, J4.P3 (CMD), MOSI.TP, R7.1, U1.5 (DI(IO0)), U2.7 (IO7)
unnamed: J2.B5, R2-USB.1
unnamed: EPD_C12.2, J1.24
unnamed: J2.A5, R2-USB1.2
unnamed: C4.1, D3.1 (K), D4.2 (A)
unnamed: CHG_LED.C, R1_BAT.1
unnamed: MCP73831.1 (STAT), R1_BAT.2
unnamed: MCP73831.5 (PROG), R2_BAT.2
unnamed: C_DELAY.1, IC1.5 (CT)
unnamed: EPD_C10.2, J1.22
unnamed: EPD_C8.2, J1.20
unnamed: EPD_C7.2, J1.19
unnamed: EPD_C6.2, J1.18
unnamed: D7.1 (CATHODE), R_CAPACITOR.1
unnamed: EPD_C2.2, J1.5
unnamed: EPD_C1.2, J1.4
PREVGH: D5.1 (K), EPD_C9.2, J1.21
PREVGL: D3.2 (A), EPD_C11.2, J1.23
RESE: J1.3, Q3.2 (S), R3.2
RESE': R2.2, R3.1, SJ1.2
RESET: C5.1, IC1.1 (VOUT), RESET_BUTTON.3, RESET_BUTTON.4, R_RESET.1, U2.3 (EN)
RTC_RST: U2.16 (IO18), U3.4 (!RST)
RX: RX.TP, U2.24 (RXD0/GPIO17)
SCK: D10.1, J1.13, J4.P5 (CLK), R6.1, SCK.TP, U1.6 (CLK), U2.6 (IO6)
SCL: J3.4, R2-PINH.1, SENSOR2.4 (SCK), U2.20 (IO22), U3.16 (SCL), U4.7 (SCL)
SDA: J3.3, R1_PINH.1, SENSOR2.3 (SDI), U2.19 (IO21), U3.15 (SDA), U4.8 (SDA)
SRC: C4.2, D5.2 (A), L1.1, Q3.3 (D)
SS_SD: D8.1, J4.P2 (CD/DAT3), R10.1, U2.4 (IO4)
TX: TX.TP, U2.25 (TXD0/GPIO16)
USB_D+: D1.1 (I/O1_1), U2.14 (IO13)
USB_D-: D1.3 (I/O2_1), U2.13 (IO12)
VBAT: C2_BAT.1, MCP73831.3 (VBAT), Q1.3 (D), U4.2 (CELL), U4.3 (VDD), VBAT.TP
VBUS: C1_BAT.1, C4_USB.1, C5_USB.1, CHG_LED.A, D1.5 (VBUS), D2.2 (ANODE), MCP73831.4 (VIN), PFMF.050.1.2, Q1.1 (G), R1_PWRUSB.2, VBUS.TP
VRTC: C8.1, C10_SUPERCAP.1, R_CAPACITOR.2, U3.14 (VBAT)
VUSB: J2.A4, J2.A9, J2.B4, J2.B9, PFMF.050.1.1

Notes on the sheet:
USB C connector & ESD protection
LDO Voltage Regulator
SD0805S020S1R0
SD Card
Display Type Selector
E-Paper Drive Circuit
Li-Po Battery Charging Controller
ESP32 C6
E-Paper Display Header
EPD POWER
DMG2305UX-7
Environmental Sensor BME688
BME688
Voltage Supervisor + Reset & Boot / IO Button
Battery Charge Level
RTC Module DS3231SN
Test Pads
Qwicc / Stemma QT
SPI ESD Protection Lines
External NOR Flash 64MB

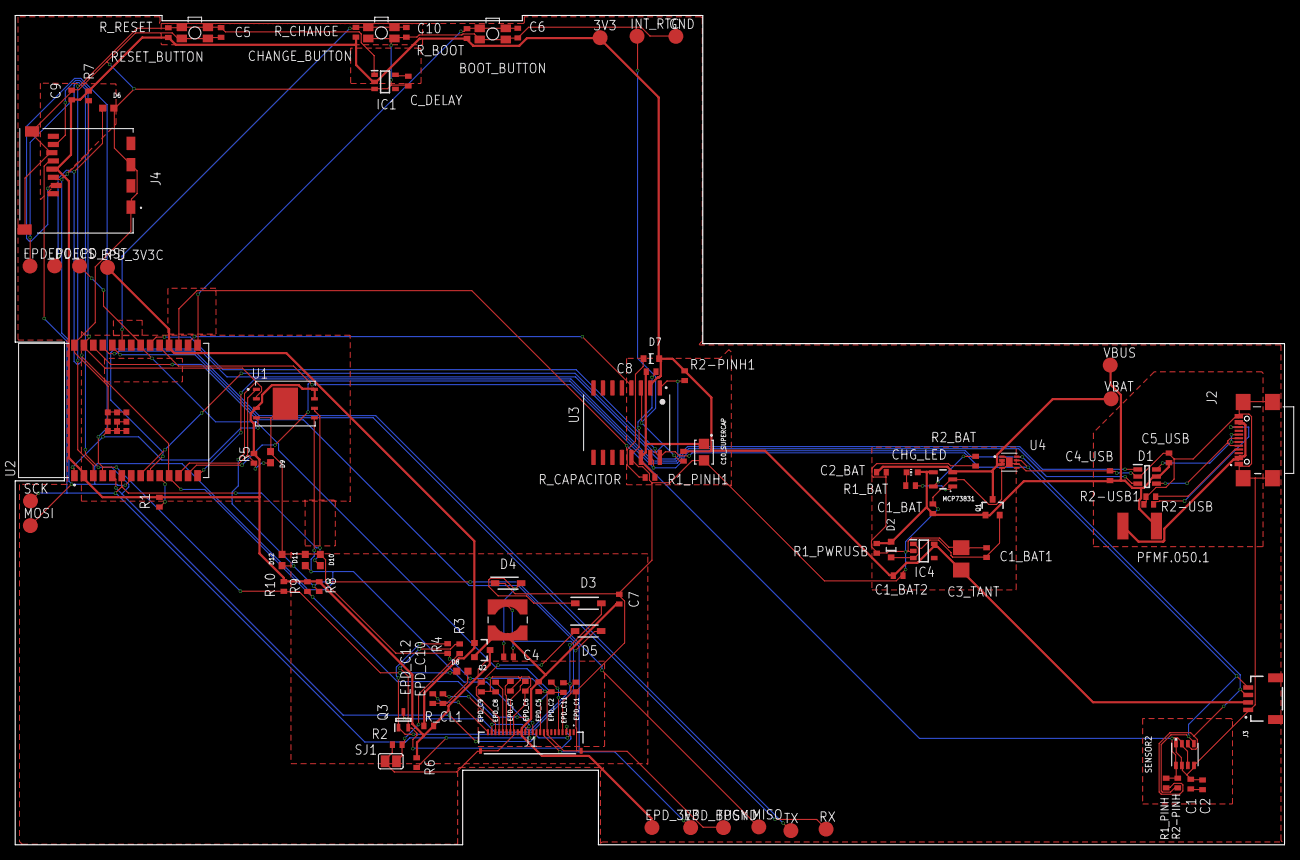
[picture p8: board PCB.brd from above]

Board: 2 copper layers, 170.2 x 111.2 mm, 103 parts (0 on the bottom side), 56 nets.

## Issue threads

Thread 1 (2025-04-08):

3D models

radum157, 2025-04-08:
Some pieces that are in use are missing a 3D CAD model. For example: Li-Po battery, 7'' display, resistors and capacitors.

Closed 2025-04-12.

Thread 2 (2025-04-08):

Fusion 3D files

radum157, 2025-04-08:
Missing the fusion file with the whole device (PCB + battery + display + enclosure assembled together) and exploded view.

Closed 2025-04-14.

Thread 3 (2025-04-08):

Documentation enhancement

radum157, 2025-04-08:
README could use some images / renderings of the PCB / final 3D device / schematic to help with the explanations.

Closed 2025-04-14.

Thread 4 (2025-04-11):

PCB thickness

radum157, 2025-04-11:
Board thickness should be 1mm, not 1.6...

Go to Rules > Preferences > Design Preferences

Edit the description for good measure.

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

Go to the Layer Stack tab and check the "Edit material properties" option. Then double click on the 1.6mm and change the text to 1mm.

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

Closed 2025-04-11.

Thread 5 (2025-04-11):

Soldermask Clearance

radum157, 2025-04-11:
There is some overlapping text on the "Names Top" / "Soldermask Top" layer.

**Try moving them around on the 2D PCB** (or removing them if they are not necessary).

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

Also on the 2D PCB, the test pads should be named according to the signal they test. **For example, "TP9" should be changed to "EPD_BUSY"**; "TP6" to "MISO" etc. **These cannot be removed, so you must change them** :(

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

Closed 2025-04-12.

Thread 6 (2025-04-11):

Via Stitching

radum157, 2025-04-11:
Your routing is done on both top and bottom. Try to do some via stitching near esp32.

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

**Make sure to select "Fill Polygon Shape" and a right angle bend type**.

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

After pressing "OK", you can move the edges of the square in any direction in order to resize the shape.

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

Closed 2025-04-11.

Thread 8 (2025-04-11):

DRC

radum157, 2025-04-11:
An air wire error is shown after running DRC. This should not be approved.

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

Here is a guide for manual routing (on the example shown above):

First off, remove the ground planes. Click on an edge of the PCB, then "Select Item" > Polygon Edge: GND > Delete: Polygon Pour. Repeat this for the other polygon edge as well.

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

Then you can begin routing. Go to Route > Manual Route and start from the pad of the first component (e.g. R2_USB).

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

To route, press click on the desired end of the route. This will then allow you to continue until you hit escape. In some cases, you might find yourself unable to reach the destination (you are surrounded by other routes on the same plane).

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

You will need vias. Before adding the end of the route, like in the image above, hit "space". This will let you choose where to place a via in the route (and effectively switch planes from top to bot or bot to top).

The end result should look something like this (look only at **N$1**).

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

After you're done, select the PCB edge and create the ground planes again. Make sure to run DRC at each step to ensure you're not breaking anything while applying this fix...

Closed 2025-04-11.

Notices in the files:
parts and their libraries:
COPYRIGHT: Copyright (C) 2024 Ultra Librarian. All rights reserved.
